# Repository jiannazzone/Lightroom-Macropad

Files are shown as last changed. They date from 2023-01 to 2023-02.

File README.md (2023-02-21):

# Lightroom Macropad

This is an attempt to make a DIY macropad for Adobe Lightroom Classic, focusing on my most-used tools. It should work with any ATMEGA board that supports HID. I used the `ATMEGA32u4` on an Arduino Pro Micro clone, and you can find many affordable options on eBay. While the macropad is designed with Lightroom in mind, you can adapt it for any program if you're handy with the Arduino IDE.

> [Lightroom keyboard shortcuts](https://helpx.adobe.com/lightroom-classic/help/keyboard-shortcuts.html)

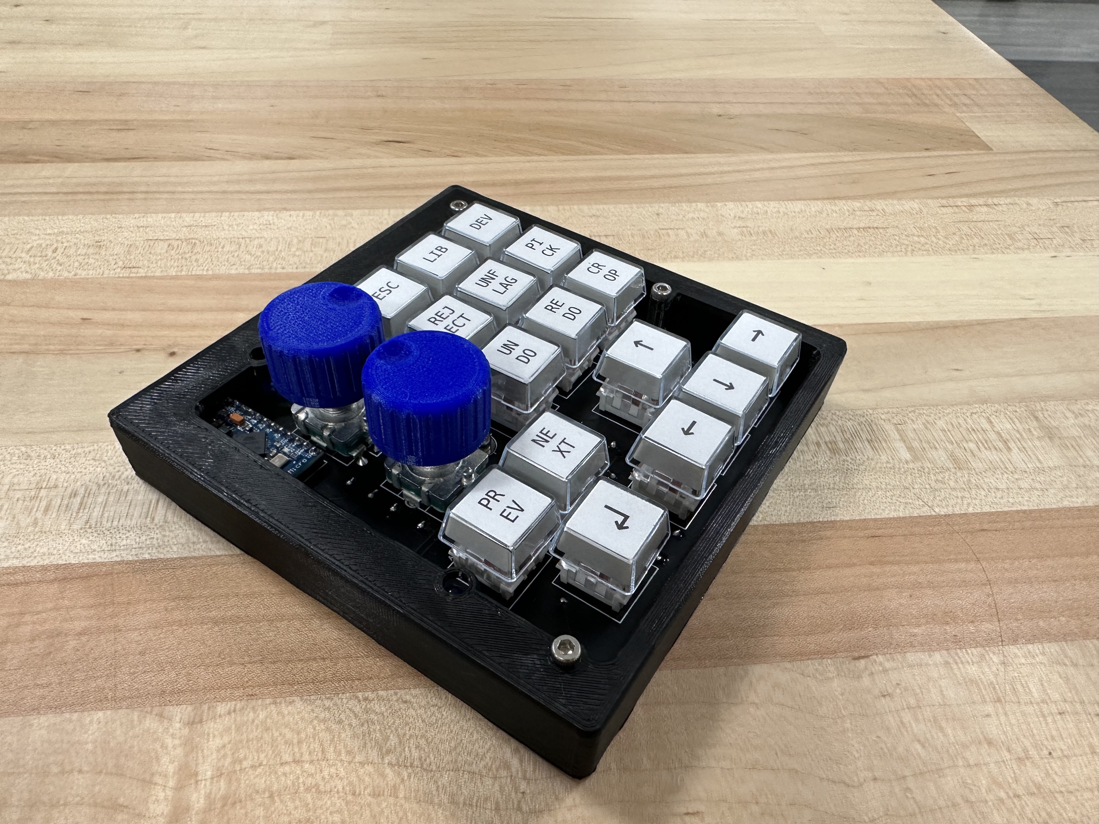
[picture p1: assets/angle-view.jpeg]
Angled View

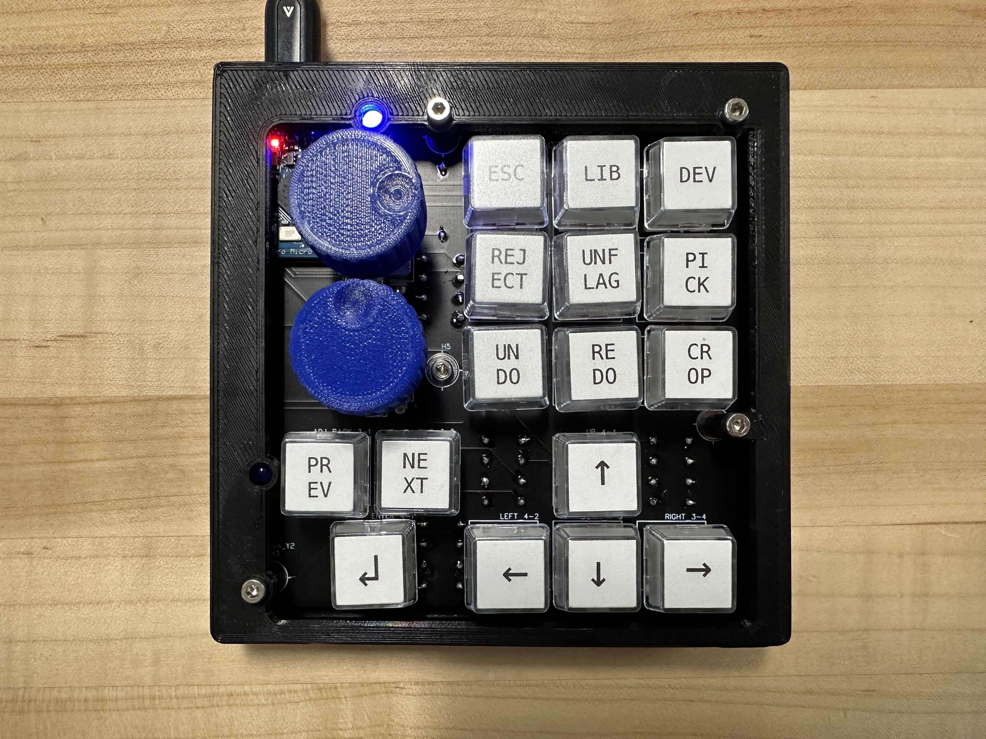
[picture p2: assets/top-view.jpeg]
Top view


## Materials
All materials listed will fit in my PCB. If you use different components, I suggest printing out the PCB 1:1 and verifying that the footprints and pinouts are the same. All components are through-hole.
- Arduino Pro Micro
- [PEC16-4220F-S0024 Rotary Encoder](https://www.digikey.com/en/products/detail/bourns-inc/PEC16-4220F-S0024/3534239) (2)
  - Includes a button for toggling Zoom level and slider adjustment speed
  - If you use a different encoder, you might need to adjust the schematic and firmware (details below, also see schematic for rotary pinout)
  - **These encoders have a long-ish shaft. If I were to do this again, I would get the [same encoder with a 15mm shaft](https://www.digikey.com/en/products/detail/bourns-inc/PEC16-4215F-S0024/3534280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).**
- MX-compatible key switches (16)
- Keycaps of your choosing (16)
  - I used the relegendable keycaps from [Adafruit](https://www.adafruit.com/product/5039) (also available on [DigiKey](https://www.digikey.com/en/products/detail/adafruit-industries-llc/5039/14313478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))
- 1N4148 diodes (16)
- 5mm LEDs (2)
- 10K-ohm resistors (4)
- 220-ohm resistors (2)

## Firmware
The [firmware](/firmware/firmware.ino) is a standard keyboard matrix (4x4), but because of the layout of the macropad, the ordering is not completely intuitive. The diagram below and included schematics should be helpful in understanding it. The encoder buttons are wired to their own dedicated pins.

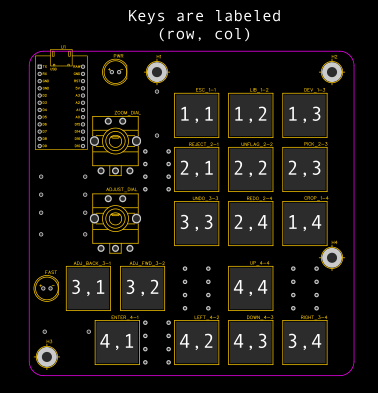
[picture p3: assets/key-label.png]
Key Labeling Diagram


If you plan to customize your macropad, please carefully read my comments in the firmware file. Since columns are actively switched through, each one gets a dedicated function for ease of understanding. You can go into each function and edit the associated shortcuts. For example:
```arduino
void firstCol(int row) {
  // Keys labeled (x, 1)
  switch (row) {
    case 0:
      Keyboard.write(KEY_ESC);
      return;
    case 1:
      Keyboard.write('x');
      return;
    case 2:
      Keyboard.write(',');
      return;
    case 3:
      Keyboard.write(KEY_RETURN);
      return;
  }
}
```
For more complicated shortcuts involving multiple key presses, you may need to use the `Keyboard.press()` method. For example, the following code is used for `UNDO`. 
```arduino
Keyboard.press(KEY_LEFT_GUI);
Keyboard.write('z');
Keyboard.releaseAll();
```
Note the use of both `Keyboard.press()` and `Keyboard.write()`. The `press` method will hold the key, while the `write` method will only activate the key once. Using `Keyboard.press('z')` for this example would result in multiple `UNDOs`.

> More information can be found on [NicoHood's repo](https://github.com/NicoHood/HID).

## PCB
The PCB was designed using [EasyEDA](https://easyeda.com). I have included their [JSON exports](/PCB/EasyEDA/) for both the schematics and PCB if you want to make changes. You can also find the live project [on EasyEDA](https://oshwlab.com/aiannazzone/lightroom).
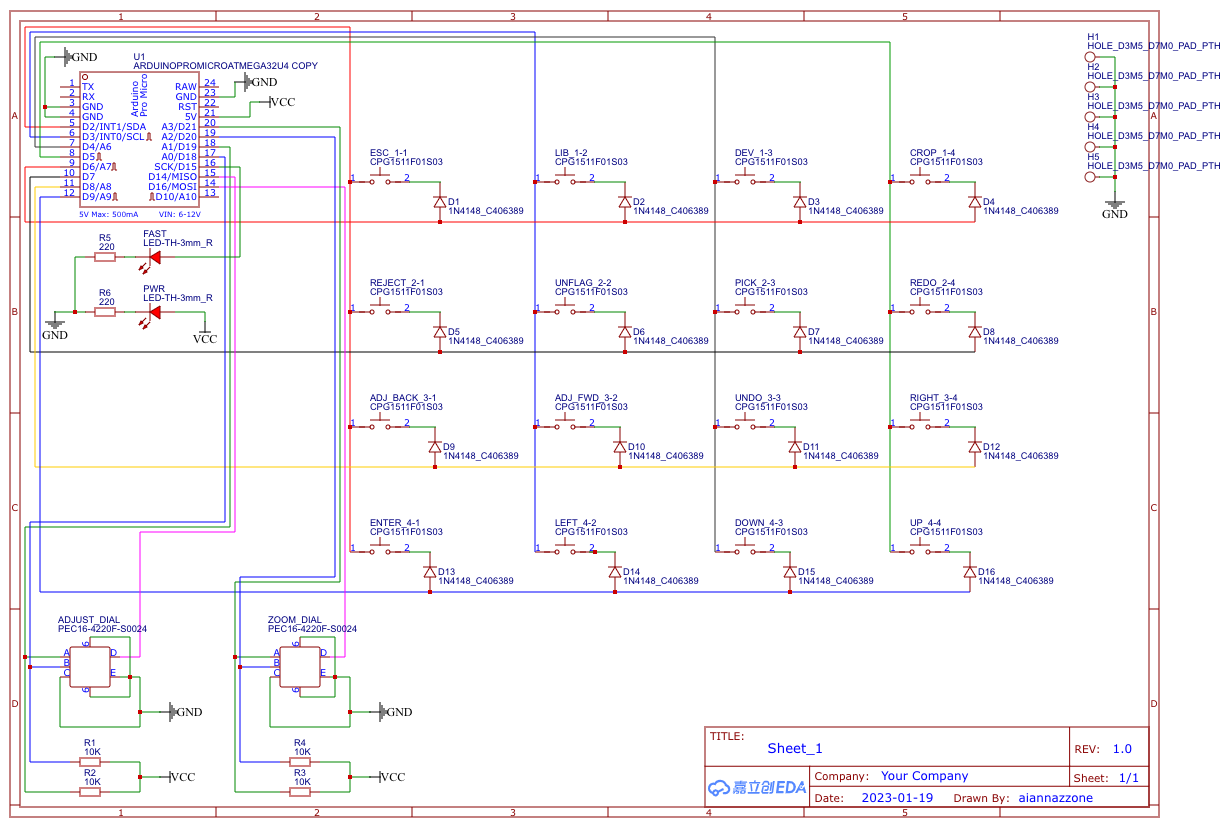
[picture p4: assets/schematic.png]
Schematic

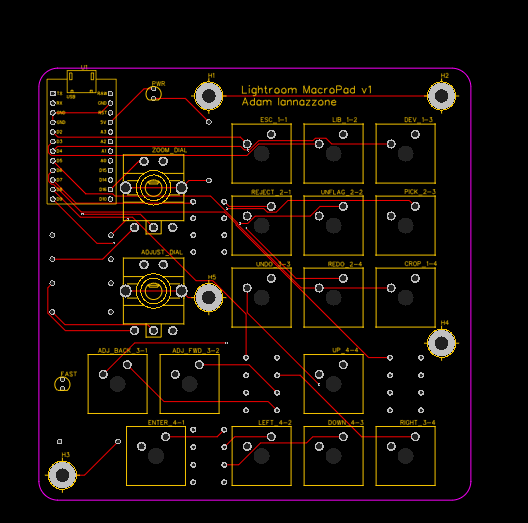
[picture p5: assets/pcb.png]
PCB


## Enclosure
- [Base](STLs/Base.stl)
- [Open-frame lid](STLs/Lid-open.stl)
- [Fusion 360](STLs/Lightroom-Macropad-Case.f3d)
> If there is interest, I might add a more closed-off lid option.

The enclosure prints in 2 halves. You will need the following hardware:
- M3x5 (1)
- M3x16 (4)

The exact lengths aren't that important. You just want them to be long enough for the teeth to grab in the plastic pillars, but not so long that the screws protrude.

The short screw secures the PCB through the central hole directly into the bottom half of the enclosure. The 4 longer screws go through the top half, through the PCB, and into the bottom half of the enclosure. The mounting holes in the PCB are slightly oversized and allow for a little adjustment if your PCB and print don't perfectly align. 

You will also want two knobs for your rotary encoders. I have [created one](/STLs/Rotary_Knob.stl) that fits nicely on the 20mm encoders, but you can use the [parametric OpenSCAD file](/STLs/Rotary_Knob.scad) to customize it however you like.

___
If you like my work, consider supporting me [via Paypal](https://www.paypal.me/jiannazzone).

___
<br />This work is licensed under a <a rel="license" href="http://creativecommons.org/licenses/by-nc-sa/4.0/">Creative Commons Attribution-NonCommercial-ShareAlike 4.0 International License</a>.

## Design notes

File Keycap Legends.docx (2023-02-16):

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
REJECT

↲

DEV

LIB

UNFLAG

ESC

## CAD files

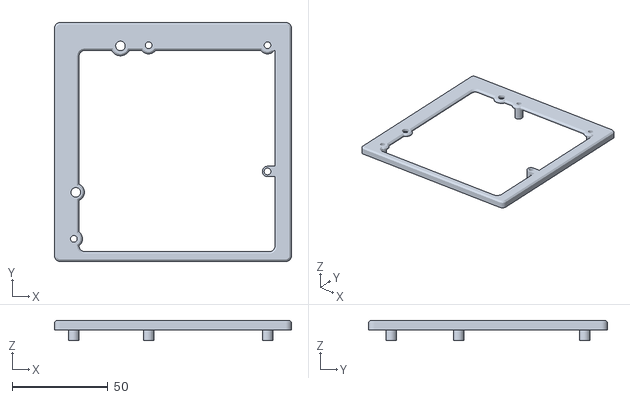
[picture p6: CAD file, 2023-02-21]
STLs/Lid-open.stl
124.1 x 125.1 x 10.7

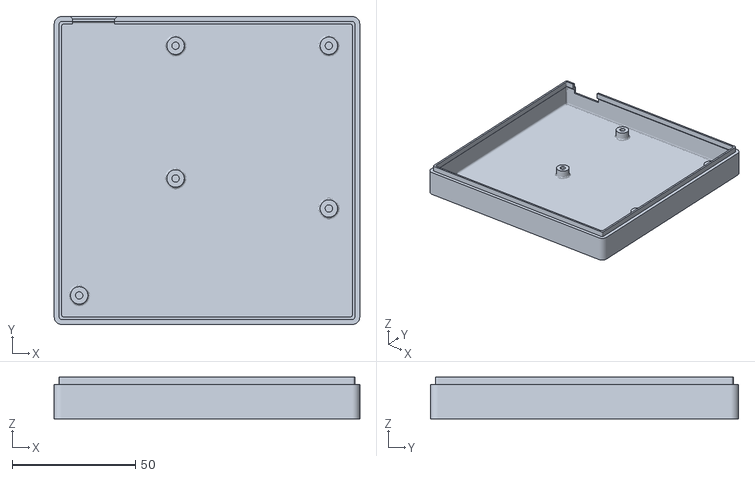
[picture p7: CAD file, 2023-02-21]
STLs/Base.stl
124.1 x 125.1 x 17.0

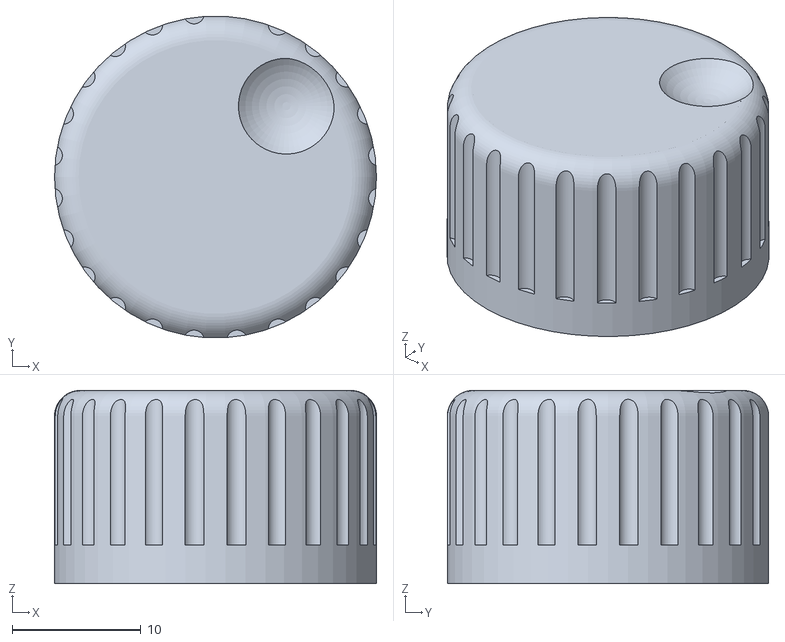
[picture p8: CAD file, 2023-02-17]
STLs/Rotary_Knob.stl
25.0 x 25.0 x 15.0

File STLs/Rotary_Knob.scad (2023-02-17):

/* [Basic] */
//Knob Diameter (mm)
knob_diameter=25; //[10:30]
//Knob Height (mm)
knob_height=15;//[10:20]
//Shaft Length (mm)
shaft_length=10;//[5:15]

/* [Customizations] */
//Finger Indent (mm)
Finger_Indent=5;//[1:10]
//Roundover (mm)
roundover=2;//[1:3]
//tolerance (mm)
tolerance=0.1;//[0,0.1,0.2,0.3]
//Side Detent Depth (mm)
detent=0.7;//[0.5:0.1:2.0]
//Detent Angle Spacing (degrees)
detent_angle=30;//[15:15:90]

/* [Hidden] */
$fn=50;

difference() {
    // Knob Body
  union() {
      cylinder(r=knob_diameter/2,h=knob_height-roundover);
      translate([0,0,knob_height-roundover]) cylinder(r=knob_diameter/2-roundover,h=roundover);
      translate([0,0,knob_height-roundover]) rotate_extrude(convexity = 10) translate([knob_diameter/2-roundover,0,0])  circle(r=roundover);
  }
  // Finger Detent
  translate([knob_diameter/2-Finger_Indent-roundover*2,knob_diameter/2-Finger_Indent-roundover,knob_height+Finger_Indent/1.5]) sphere(r=Finger_Indent);
  
  // Side Detents
  for (i=[0:detent_angle:360]) translate([(knob_diameter+0.6)*sin(i)/2,(knob_diameter+0.6)*cos(i)/2,3]) cylinder(r=detent,h=knob_height);
  difference() {
      translate([0,0,2]) cylinder(r=3.1+tolerance,h=shaft_length-2);
      translate([-5,-6.6-tolerance,2]) cube([10,5,shaft_length-2]);
  }
  
  // Shaft Hole
  difference() {
      cylinder(r=3+tolerance,h=2);
      translate([-5,-6.5-tolerance,0]) cube([10,5,shaft_length-2]);
  }
}

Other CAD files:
STLs/Lightroom-Macropad-Case.f3d

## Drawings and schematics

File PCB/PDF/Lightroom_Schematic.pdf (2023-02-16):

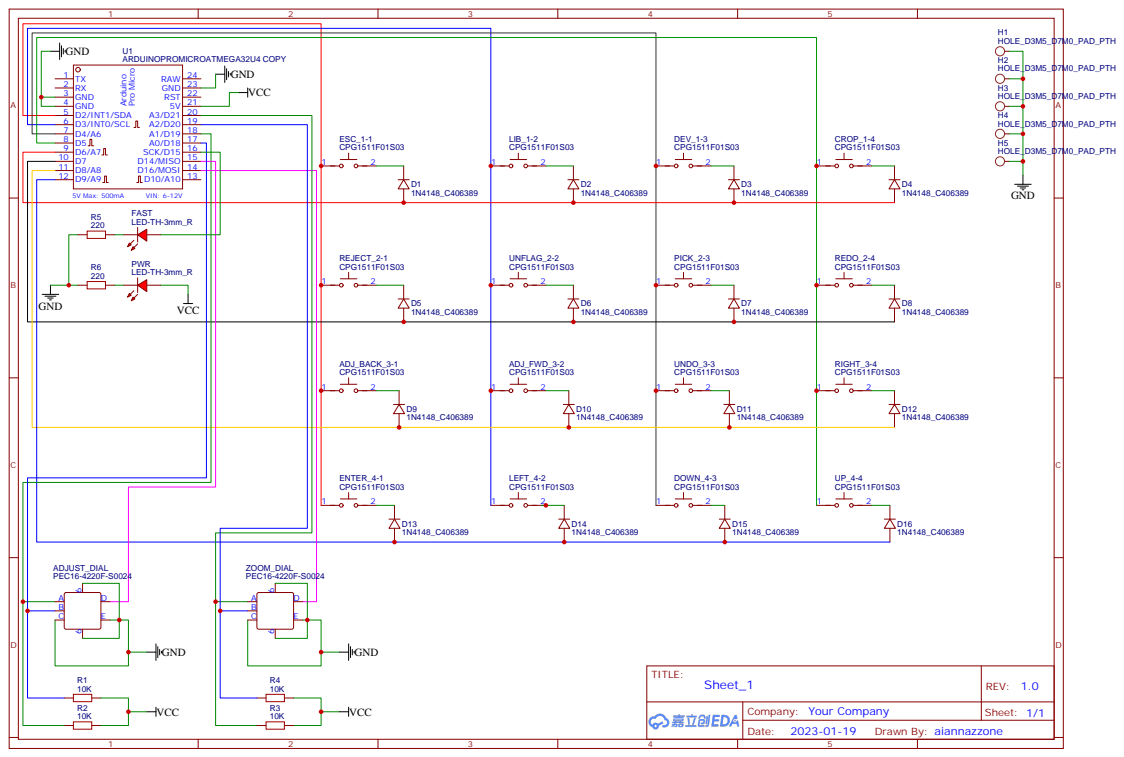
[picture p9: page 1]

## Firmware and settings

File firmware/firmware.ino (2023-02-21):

/*
Lightroom Macropad by Adam Iannazzone
Keyboard matrix code adapted from: https://www.baldengineer.com/arduino-keyboard-matrix-tutorial.html
*/

#include <HID-Project.h> // https://github.com/NicoHood/HID
#include <ClickEncoder.h> // https://github.com/0xPIT/encoder/blob/master/ClickEncoder.h
#include <TimerOne.h> // https://github.com/PaulStoffregen/TimerOne
#include <TimerThree.h> // https://github.com/PaulStoffregen/TimerThree

// Encoder Definitions
const int adjustSW = 14;
int adjustClickState = HIGH;
const int adjustDT = A0;
const int adjustCLK = A1;

ClickEncoder *adjustEncoder;
int adjustLast, adjustVal;

const int zoomSW = 16;
int zoomClickState = HIGH;
const int zoomDT = A2;
const int zoomCLK = A3;

int zoomLast, zoomVal;
ClickEncoder *zoomEncoder;

// LED Definitions
bool fastMode = false;
const int fastLED = 15;

// Inputs
byte rows[] = { 6, 7, 8, 9};
const int rowCount = sizeof(rows) / sizeof(rows[0]);

// Outputs
byte cols[] = { 2, 3, 4, 5 };
const int colCount = sizeof(cols) / sizeof(cols[0]);

// Variables for tracking key state (to prevent duplicate presses)
byte lastKeyState[colCount][rowCount];
byte currentKeyState[colCount][rowCount];

// Friendly key descriptions for printing to serial
String keyCodes[colCount][rowCount] = {
  { "ESC", "Reject", "Adjust Back", "Enter" }, // Keys labeled (x, 1)
  { "Library", "Unflag", "Adjust Forward", "Left" }, // Keys labeled (x, 2)
  { "Develop", "Pick", "Undo", "Down" }, // Keys labeled (x, 3)
  { "Crop", "Redo", "Right", "Up" } // Keys labeled (x, 4)
};

// Timers for each encoder. ClickEncoder takes care of system interrupts
void adjustTimerIsr() {
  adjustEncoder->service();
}

void zoomTimerIsr() {
  zoomEncoder->service();
}

void setup() {
  Serial.begin(9600);

  // Initialize HID keyboard
  Keyboard.begin();

  // Set up ClickEncoders. Each one needs its own timer.
  adjustEncoder = new ClickEncoder(adjustDT, adjustCLK, adjustSW, 4);
  Timer1.initialize(1000);
  Timer1.attachInterrupt(adjustTimerIsr);
  adjustLast = -1;

  zoomEncoder = new ClickEncoder(zoomDT, zoomCLK, zoomSW, 4);
  Timer3.initialize(1000);
  Timer3.attachInterrupt(zoomTimerIsr);
  zoomLast = -1;

  // Set pinModes for rows and columns
  for (int x = 0; x < rowCount; x++) {
    pinMode(rows[x], INPUT);
  }

  for (int x = 0; x < colCount; x++) {
    pinMode(cols[x], INPUT_PULLUP);
  }
  pinMode(fastLED, OUTPUT);
}

void checkAdjustEncoder() {
  // Push Button
  ClickEncoder::Button b = adjustEncoder->getButton();
  if (b != ClickEncoder::Open) {
    if (b = ClickEncoder::Clicked) {
      fastMode = !fastMode;
      digitalWrite(fastLED, fastMode);
    }
  }

  // Encoder Rotation
  adjustVal += adjustEncoder->getValue();
  if (adjustLast < adjustVal) {
    if (fastMode) {
      Keyboard.write('+');
    } else {
      Keyboard.write('=');
    }
  } else if (adjustLast > adjustVal){
    if (fastMode) {
      Keyboard.write('_');
    } else {
      Keyboard.write('-');
    }
  }
  adjustLast = adjustVal;
}

void checkZoomEncoder() {
  // Push Button
  ClickEncoder::Button c = zoomEncoder->getButton();
  if (c != ClickEncoder::Open) {
    if (c = ClickEncoder::Clicked) {
      Keyboard.write(' ');
    }
  }

  // Encoder Rotation
  zoomVal += zoomEncoder->getValue();
  if (zoomLast < zoomVal) {
    Keyboard.press(KEY_LEFT_GUI);
    Keyboard.write('=');
  } else if (zoomLast > zoomVal) {
    Keyboard.press(KEY_RIGHT_GUI);
    Keyboard.write('-');
  }
  Keyboard.releaseAll();
  zoomLast = zoomVal;
}

void readMatrix() {
  // Iterate through each column
  for (int colIndex = 0; colIndex < colCount; colIndex++) {
    byte curCol = cols[colIndex];
    pinMode(curCol, OUTPUT);
    digitalWrite(curCol, LOW);

    // Iterate through each row for this column only
    for (int rowIndex = 0; rowIndex < rowCount; rowIndex++) {
      byte rowCol = rows[rowIndex];
      pinMode(rowCol, INPUT_PULLUP);
      currentKeyState[colIndex][rowIndex] = digitalRead(rowCol);

      // Check if key is pressed
      if (currentKeyState[colIndex][rowIndex] == LOW) {
        // Ensure that current key state differs from previous state. This will avoid duplicate presses
        // Remove this inner if-statement if you want to allow burst mode
        if (keyCodes[colIndex][rowIndex] != "" && lastKeyState[colIndex][rowIndex] == HIGH) {
          executeCommand(colIndex, rowIndex);
        }
      }

      // Update key states
      lastKeyState[colIndex][rowIndex] = currentKeyState[colIndex][rowIndex];
      
      // Disable row
      pinMode(rowCol, INPUT);
    }

    // Disable column
    pinMode(curCol, INPUT);
  }
}

void executeCommand(int col, int row) {
  String thisCode = keyCodes[col][row];
  Serial.println(thisCode);

  // Go to appropriate function for active column
  switch (col) {
    case 0:
      // Keys labeled (x, 1)
      firstCol(row);
      break;
    case 1:
      // Keys labeled (x, 2)
      secondCol(row);
      break;
    case 2:
      // Keys labeled (x, 3)
      thirdCol(row);
      break;
    case 3:
      // Keys labeled (x, 4)
      fourthCol(row);
      break;
  } // switch
} // executeCommand

/*
Each function below represents one column in the keyboard matrix.
You will need to modify the keypresses for each item if you want to alter the macropad.
NOTE: The rows and columns do NOT directly correspond to they key layout.
Refer to the diagram at https://github.com/jiannazzone/Lightroom-Macropad for more information.
*/
void firstCol(int row) {
  // Keys labeled (x, 1)
  switch (row) {
    case 0:
      Keyboard.write(KEY_ESC);
      return;
    case 1:
      Keyboard.write('x');
      return;
    case 2:
      Keyboard.write(',');
      return;
    case 3:
      Keyboard.write(KEY_RETURN);
      return;
  }
}

void secondCol(int row) {
  // Keys labeled (x, 2)
  switch (row) {
    case 0:
      Keyboard.press(KEY_LEFT_GUI);
      Keyboard.press(KEY_LEFT_ALT);
      Keyboard.write('1');
      Keyboard.releaseAll();
      return;
    case 1:
      Keyboard.write('u');
      return;
    case 2:
      Keyboard.write('.');
      return;
    case 3:
      Keyboard.write(KEY_LEFT_ARROW);
      return;
  }
}

void thirdCol(int row) {
  // Keys labeled (x, 3)
  switch (row) {
    case 0:
      Keyboard.press(KEY_LEFT_GUI);
      Keyboard.press(KEY_LEFT_ALT);
      Keyboard.write('2');
      Keyboard.releaseAll();
      return;
    case 1:
      Keyboard.write('p');
      return;
    case 2:
      Keyboard.press(KEY_LEFT_GUI);
      Keyboard.write('z');
      Keyboard.releaseAll();
      return;
    case 3:
      Keyboard.write(KEY_DOWN_ARROW);
      return;
  }
}

void fourthCol(int row) {
  // Keys labeled (x, 4)
  switch (row) {
    case 0:
      Keyboard.write('r');
      return;
    case 1:
      Keyboard.press(KEY_LEFT_SHIFT);
      Keyboard.press(KEY_LEFT_GUI);
      Keyboard.write('z');
      Keyboard.releaseAll();
    case 2:
      Keyboard.write(KEY_RIGHT_ARROW);
      return;
    case 3:
      Keyboard.write(KEY_UP_ARROW);
      return;
  }
}

void loop() {
  readMatrix();
  checkAdjustEncoder();
  checkZoomEncoder();
}

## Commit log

2023-01-30 Fix erroneous firmware file
    [firmware.ino]
2023-02-03 Update firmware.ino
    Fix commenting
    Remove extraneous debugging function
    [firmware.ino]
2023-02-16 Add assets
    - EasyEDA PCB and Schematic JSONs
    - PDFs
    - PNG assets
2023-02-17 - Add rotary knobs
    [Rotary_Knob.scad, Rotary_Knob.stl]
2023-02-21 Add STLs and update README
    [Base.stl, Lid-open.stl, Lightroom-Macropad-Case.f3d]
2023-02-21 Update firmware.ino
    Fix adjustment wheel direction being backwards
    [firmware.ino]
